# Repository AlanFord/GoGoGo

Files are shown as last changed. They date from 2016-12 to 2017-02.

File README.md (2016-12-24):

# GoGoGo
These projects support the GoGoGo module of the Contextual Electronics course.

The MotorDrive is a circuit board design that supports a brushed DC motor driver.

The EncoderBoard is a circuit board design that supports an optical motor encoder suitable for use with an encoder wheel (see below).

The EncoderWheel is the design for an encoder wheel that will fit the Sparkfun Shadow chasis (ROB-13301) and a Sparkfun 140 RPM hobby gearmotor (ROB-13302).

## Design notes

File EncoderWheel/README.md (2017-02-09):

# Encoder Wheel Design Notes

The basic design was created in Fusion 360.  The DXF file was created by making a new sketch from the surface of the part and exporting the sketch as a DXF file.

The .rd and .rld files are generated by importing the DXF file into RDWorksV8 for a Boss laser cutter.  Note that the final laser part was cut from 2mm clear acrylic using a kerf, or "sew width" of 0.28 mm.

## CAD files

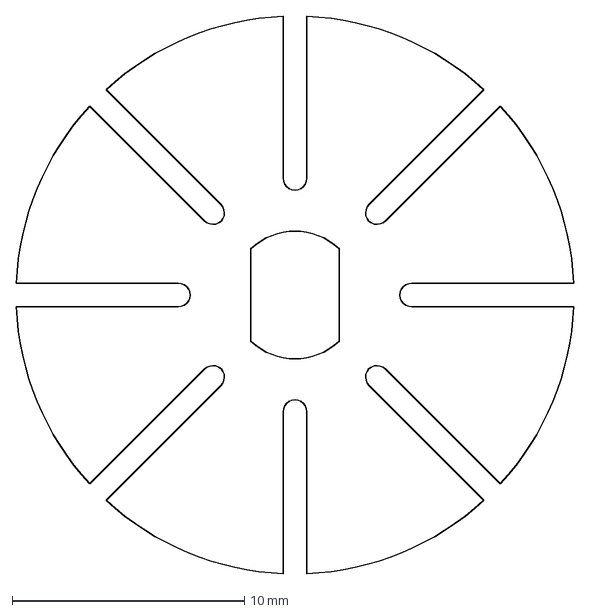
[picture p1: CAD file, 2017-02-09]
EncoderWheel/encoder-wheel-Rev2.dxf
24.0 x 24.0 mm

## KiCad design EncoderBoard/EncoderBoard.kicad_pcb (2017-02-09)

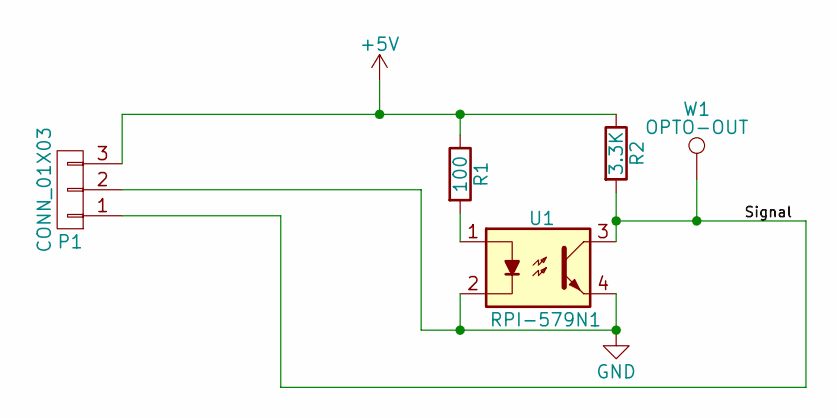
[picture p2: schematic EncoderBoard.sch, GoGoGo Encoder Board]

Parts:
P1: CONN_01X03; Pin_Header_Angled_1x03
R1: 100; R_0805_HandSoldering
R2: 3.3K; R_0805_HandSoldering
U1: RPI-579N1
W1: OPTO-OUT; Measurement_Point_Square-SMD-Pad_Big

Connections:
+5V: P1.3, R1.1, R2.1
/Signal: P1.1, R2.2, U1.3, W1.1
GND: P1.2, U1.2, U1.4
unnamed: R1.2, U1.1

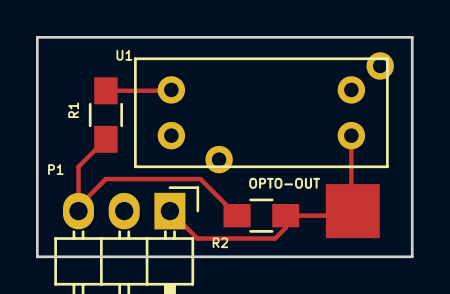
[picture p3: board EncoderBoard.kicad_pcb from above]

Board: 2 copper layers, 20.8 x 12.2 mm, 5 parts (0 on the bottom side), 4 nets.

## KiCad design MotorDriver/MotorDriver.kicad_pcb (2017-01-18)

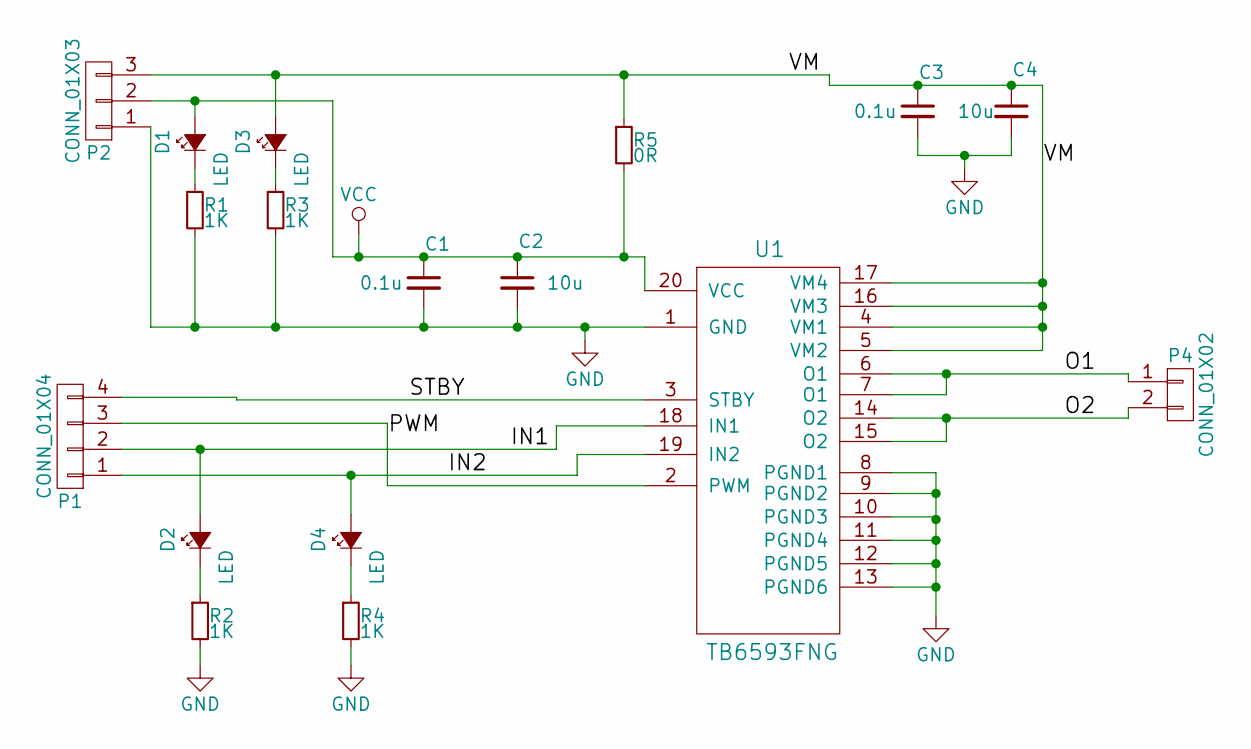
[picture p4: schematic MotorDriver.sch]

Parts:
C1, C3: 0.1u; C_0805
C2, C4: 10u; C_1206_HandSoldering
D1, D2, D3, D4: LED; LED_0805
P1: CONN_01X04; Pin_Header_Straight_1x04
P2: CONN_01X03; Pin_Header_Straight_1x03
P4: CONN_01X02; Pin_Header_Straight_1x02
R1, R2, R3, R4: 1K; R_0805_HandSoldering
R5: 0R; R_0805
U1: TB6593FNG; SSOP-20

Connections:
/IN1: D2.2 (A), P1.2, U1.18 (IN1)
/IN2: D4.2 (A), P1.1, U1.19 (IN2)
/O1: P4.1, U1.6 (O1), U1.7 (O1)
/O2: P4.2, U1.14 (O2), U1.15 (O2)
/PWM: P1.3, U1.2 (PWM)
/STBY: P1.4, U1.3 (STBY)
/VM: C3.1, C4.1, D3.2 (A), P2.3, R5.1, U1.4 (VM1), U1.5 (VM2), U1.16 (VM3), U1.17 (VM4)
GND: C1.2, C2.2, C3.2, C4.2, P2.1, R1.2, R2.2, R3.2, R4.2, U1.1 (GND), U1.8 (PGND1), U1.9 (PGND2), U1.10 (PGND3), U1.11 (PGND4), U1.12 (PGND5), U1.13 (PGND6)
unnamed: D1.1 (K), R1.1
unnamed: D2.1 (K), R2.1
unnamed: D3.1 (K), R3.1
unnamed: D4.1 (K), R4.1
VCC: C1.1, C2.1, D1.2 (A), P2.2, R5.2, U1.20 (VCC)

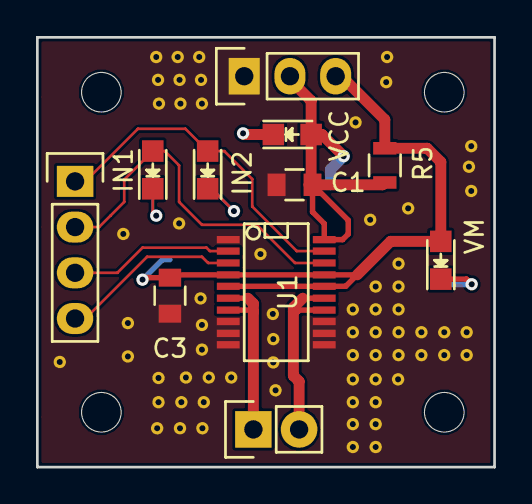
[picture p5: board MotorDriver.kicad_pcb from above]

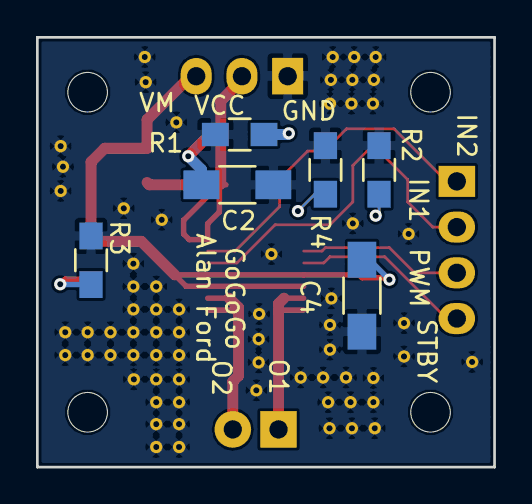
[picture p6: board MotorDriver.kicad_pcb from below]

Board: 2 copper layers, 25.4 x 23.9 mm, 17 parts (6 on the bottom side), 13 nets.

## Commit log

2016-12-24 added encode wheel design objectives
2016-12-24 updaed encoder wheel dimensions
2016-12-25 added encoder wheel measurements and initialized KiCad files
    [EncoderBoard.kicad_pcb, EncoderBoard.sch, MotorDriver.kicad_pcb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]
2016-12-26 first attempt at pcb layout
    [EncoderBoard.kicad_pcb, EncoderBoard.sch]
2016-12-28 generate gerbers
    [EncoderBoard-B.Cu.gbl, EncoderBoard-B.Mask.gbs, EncoderBoard-B.SilkS.gbo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]
2017-01-15 initial motor driver board layout and traces
    [MotorDriver.kicad_pcb, MotorDriver.sch]
2017-01-18 finished motor driver layout and generated gerbers
    [MotorDriver-B.Cu.gbl, MotorDriver-B.Mask.gbs, MotorDriver-B.Paste.gbp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]
2017-01-18 adjusted soldermask and updated gerbers
    [EncoderBoard-B.Cu.gbl, EncoderBoard-B.Mask.gbs, EncoderBoard-B.SilkS.gbo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]
2017-01-18 zipped gerbers
2017-02-09 changed the pull up resistor to 3.3K
    [EncoderBoard.kicad_pcb, EncoderBoard.sch]
2017-02-09 initial design of encoder wheel for laser cutter and gcode for Othermill
    [encoder-wheel-Rev2.dxf]
